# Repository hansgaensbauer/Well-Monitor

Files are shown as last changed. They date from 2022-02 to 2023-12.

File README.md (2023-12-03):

# Well Monitor
Well monitoring equipment for Engineers Without Borders

This hardware is for projects that require more monitoring than is possible with manual measurements taken by community members. The well monitor works by weighing a pipe or other weight suspended within the well, since the apparent weight of the pipe is directly proportional to the amount of the pipe left above water.

A photo of the well monitors before packaging
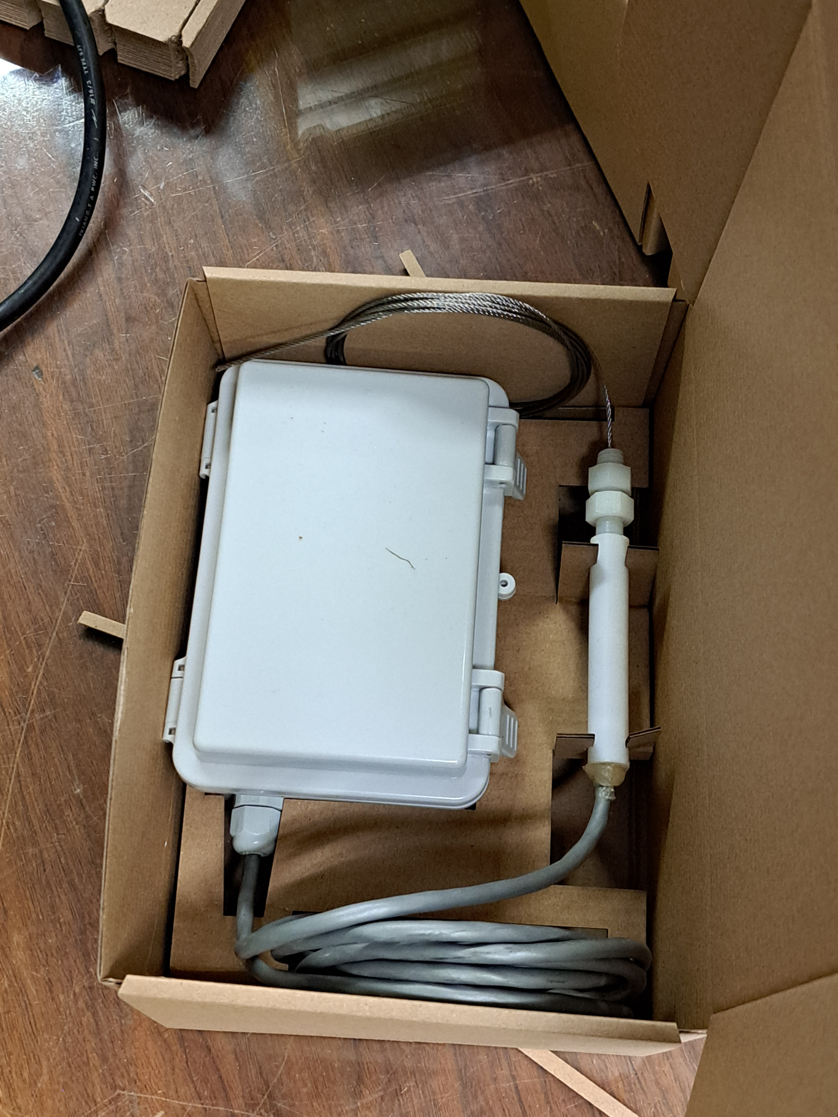
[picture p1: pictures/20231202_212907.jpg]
A well monitor in its packaging


## Installation and Use
The well monitor consists of two parts: a small "probe" that contains the load cell for weighing the pipe, and a separate box with the battery, USB flash drive, and readout electronics that gets mounted nearby. The probe requires a 3/8" hole to be drilled in the well cap over the location where the pipe is to be suspended. Remove one of the acetyl nuts on the bottom of the probe, thread the stainless-steel cable through the hole in the well cap, and reattach the nut on the other side to secure the probe. Mount the electronics box vertically against a wall or to a pole driven into the ground nearby. 

Since each well installation is different, the well monitor needs to be calibrated during installation:
1. Estimate the amount of pipe required to span the maximum expected variation in water level.
2. Calculate the maximum expected weight. This is the weight of the pipe and the cable used to suspend the pipe
3. Calculate the minimum expected weight. Calculate the buoyant force on the pipe with the water level at its highest expected level, and subtract this from the maximum weight.
4. Fill jugs of water to create "dummy" weights equal to the maximum and minimum weights, and one more equal to the difference between the maximum and minimum weights.
5. Disconnect the battery for the well monitor and remove the plastic cover that covers the electronics within the waterproof box.
6. Using clip leads, apply 9V to the indicated positions on the well monitor.
7. Use a multimeter to measure the voltage on the "Vout" testpoint indicated in the diagram.
8. Turn the "gain" potentiometer all the way to the left (counterclockwise).
9. Turn the "bias" potentiometer until the voltage on the multimeter just begins to increase above zero. Try to get the potentiometer to the very edge of the point where the voltage begins to increase.
10. Suspend the "difference" weight dummy from the well monitor. Ajust the "gain" potentiometer until the voltage reads close to 3.3V (it is clamped so that it cannot exceed this voltage).
11. Suspend the "minimum" weight dummy from the well monitor. Repeat step 9 to set the proper "zero weight" point.
12. Suspend the "maximum" weight dummy from the well monitor. The voltage should be near 3.3V. Make small adjustments to the gain and offset so that the voltage is as close as possible to zero when the minimum weight is attached, and as close as possible to 3.3V when the maximum weight is attached.

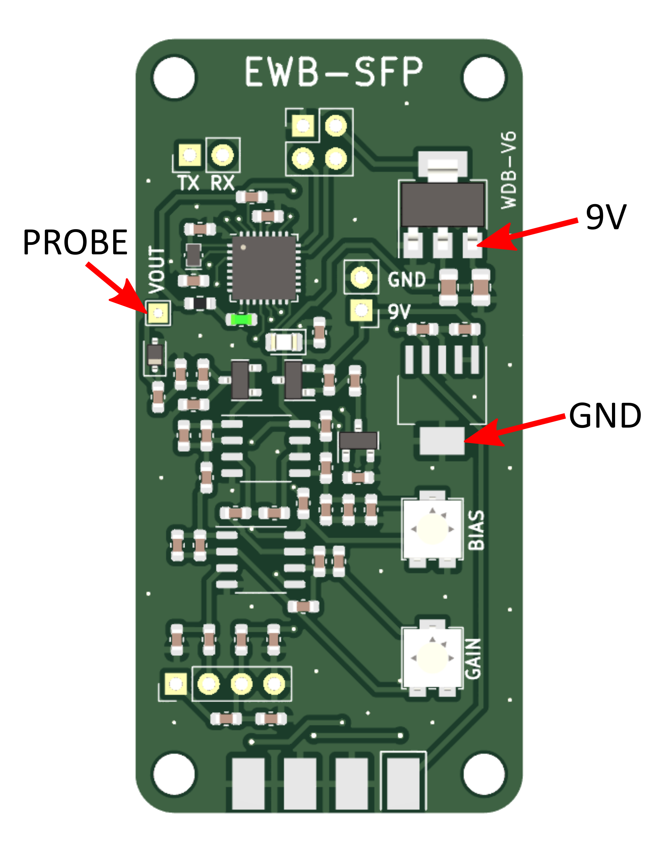
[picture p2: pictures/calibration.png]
Calibration Diagram


Once the battery is connected, measurements are saved once every three hours to a USB flash drive. To read the data, remove the flash drive and connect it to a computer. The file 'welldata.txt' will contain one line for each measurement, consisting of a measurement counter (to keep track of when measurements are restarted) followed by the measurement. The measurements are in "ADC Counts": a reading of 0 corresponds to zero volts, or the maximum water level when the well monitor is calibrated. A value of 32768 corresponds to 3.3V, or the minimum water level when the well monitor is calibrated.

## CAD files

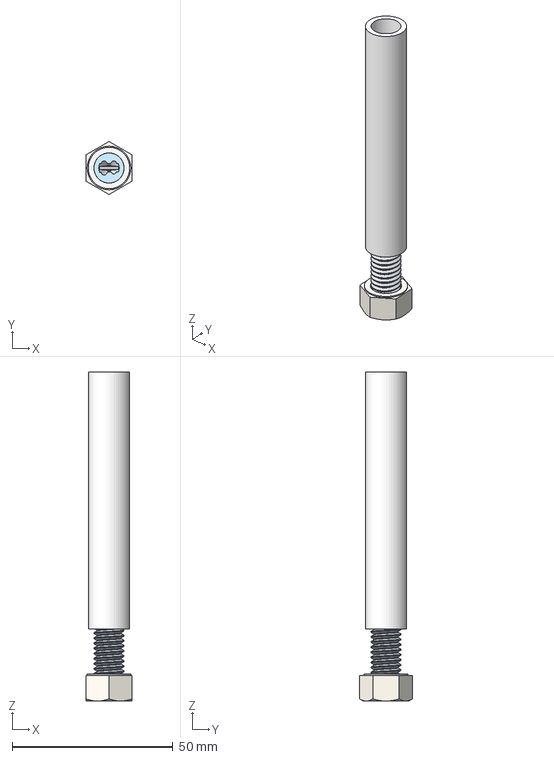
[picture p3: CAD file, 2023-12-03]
mechanical/WellMonitor_Probe.step
14.3 x 16.5 x 102.4 mm

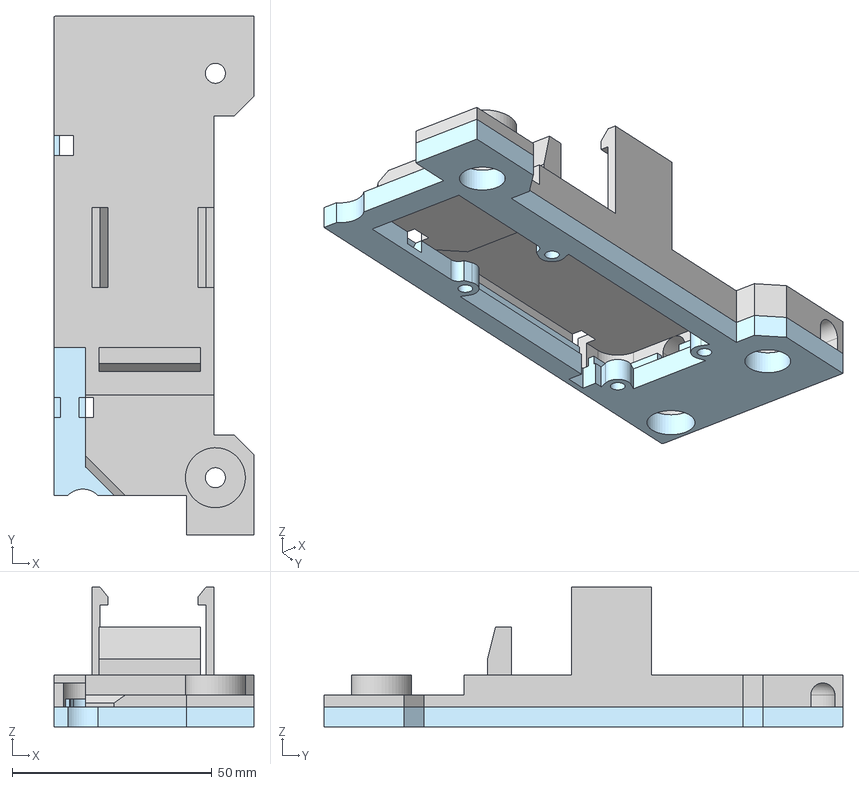
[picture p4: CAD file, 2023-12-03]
mechanical/WellMonitor_Case.step
50.0 x 129.7 x 35.0 mm

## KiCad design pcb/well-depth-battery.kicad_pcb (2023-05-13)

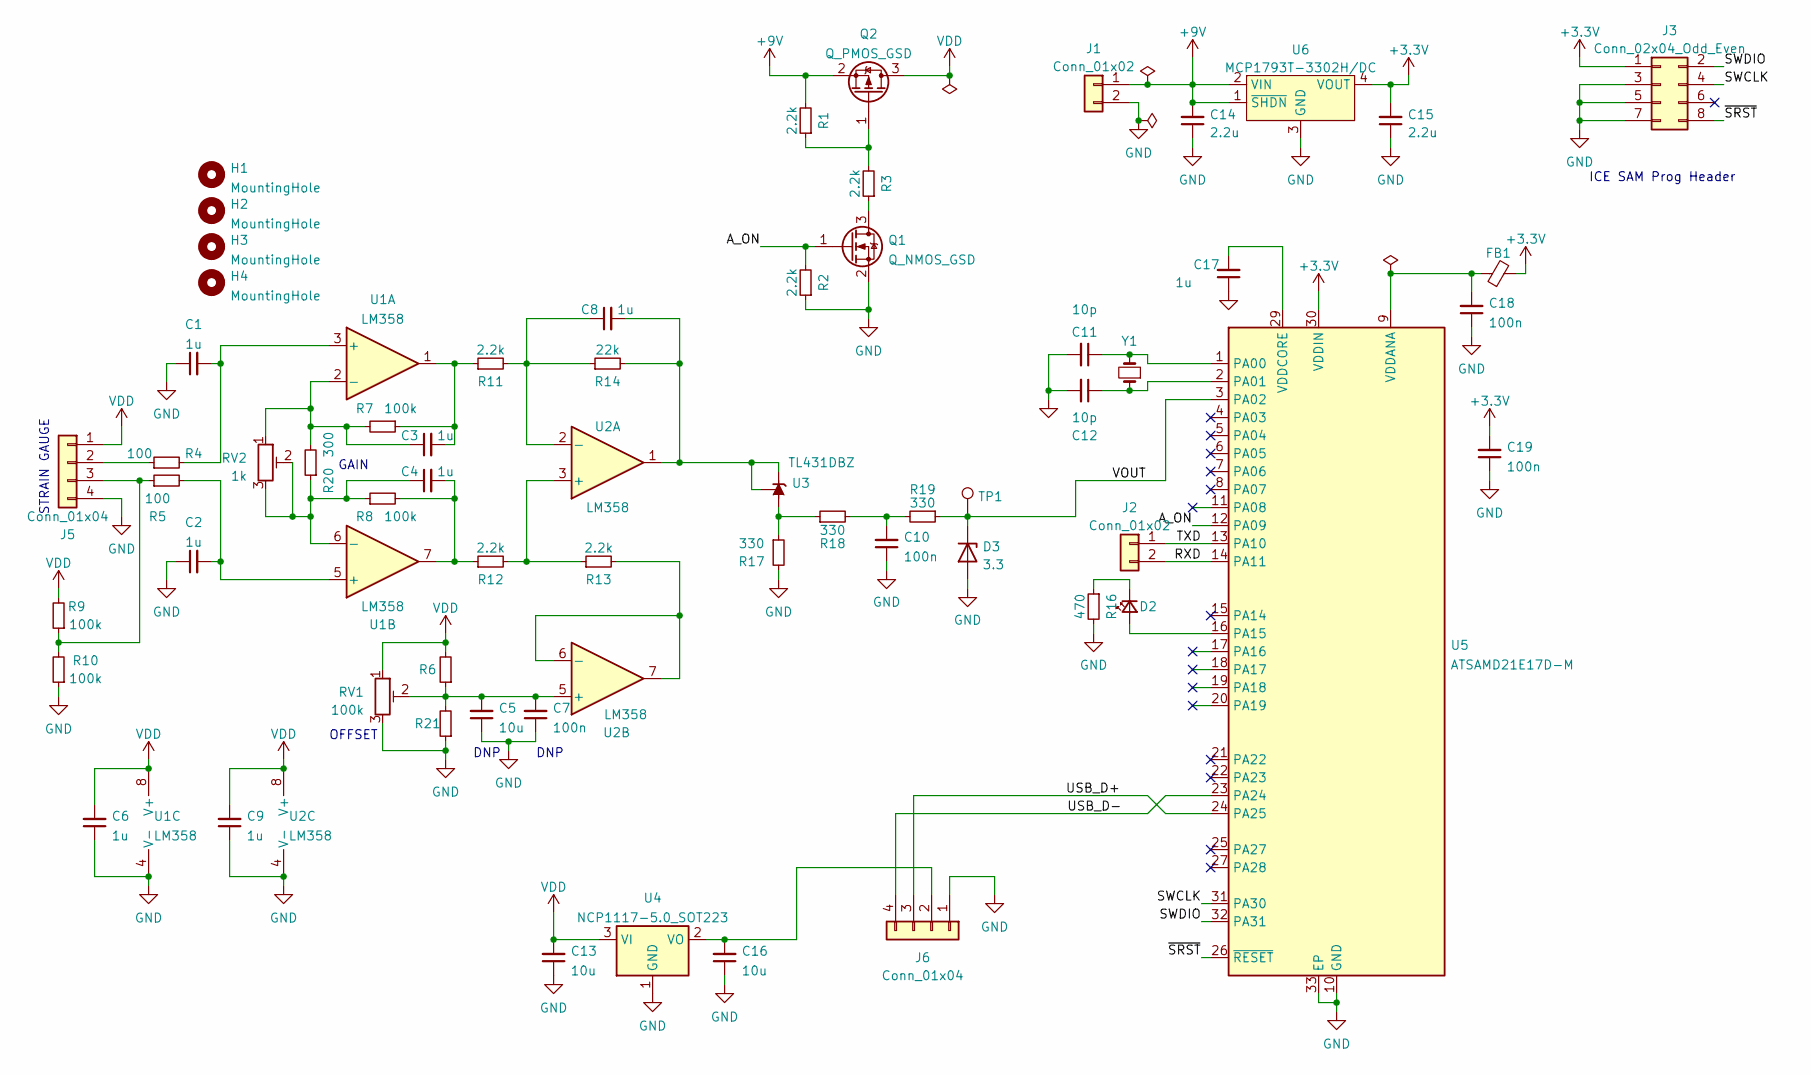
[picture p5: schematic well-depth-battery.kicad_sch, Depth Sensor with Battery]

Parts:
C1, C2, C3, C4, C6, C8, C9, C17: 1u; C_0603_1608Metric
C5: 10u; C_0603_1608Metric
C7, C10, C18, C19: 100n; C_0603_1608Metric
C11, C12: 10p; C_0603_1608Metric
C13, C16: 10u; C_0805_2012Metric
C14, C15: 2.2u; C_0603_1608Metric
D2: LED_Small; LED_0805_2012Metric
D3: 3.3; D_SOD-323
FB1: FerriteBead_Small; R_0603_1608Metric
H1, H2, H3, H4: MountingHole; MountingHole_3.2mm_M3
J1, J2: Conn_01x02; PinHeader_1x02_P2.54mm_Vertical
J3: Conn_02x04_Odd_Even; CardEdge_Prog
J5: Conn_01x04; PinHeader_1x04_P2.54mm_Vertical
J6: Conn_01x04; PinHeader_2x02_P2.54mm_Vertical
Q1: Q_NMOS_GSD; SOT-23
Q2: Q_PMOS_GSD; SOT-23
R1, R2, R3, R11, R12, R13: 2.2k; C_0603_1608Metric
R4, R5: 100; C_0603_1608Metric
R6, R21: C_0603_1608Metric
R7, R8, R9, R10: 100k; C_0603_1608Metric
R14: 22k; C_0603_1608Metric
R16: 470; C_0603_1608Metric
R17, R18, R19: 330; C_0603_1608Metric
R20: 300; C_0603_1608Metric
RV1: 100k; Potentiometer_Bourns_3314J_Vertical
RV2: 1k; Potentiometer_Bourns_3314J_Vertical
TP1: TestPoint; TestPoint_THTPad_1.5x1.5mm_Drill0.7mm
U1, U2: LM358; SOP-8_3.9x4.9mm_P1.27mm
U3: TL431DBZ; SOT-23
U4: NCP1117-5.0_SOT223; SOT-223-3_TabPin2
U5: ATSAMD21E17D-M; QFN-32-1EP_5x5mm_P0.5mm_EP3.6x3.6mm
U6: MCP1793T-3302H/DC; SOT-223-6
Y1: Crystal_Small; Crystal_SMD_MicroCrystal_CM9V-T1A-2Pin_1.6x1.0mm

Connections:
+3.3V: C15.2, C19.2, FB1.2, J3.1, U5.30 (VDDIN), U6.4 (VOUT)
+9V: C14.2, J1.1, Q2.2 (S), R1.2, U6.1 (~SHDN), U6.2 (VIN)
/A_ON: Q1.1 (G), R2.2, U5.12 (PA09)
/RXD: J2.2, U5.14 (PA11)
/SWCLK: J3.4, U5.31 (PA30)
/SWDIO: J3.2, U5.32 (PA31)
/TXD: J2.1, U5.13 (PA10)
/USB_D+: J6.3, U5.24 (PA25)
/USB_D-: J6.4, U5.23 (PA24)
/VOUT: D3.1 (K), R19.1, TP1.1, U5.3 (PA02)
/~SRST: J3.8, U5.26 (~RESET)
GND: C1.1, C2.1, C5.1, C6.1, C7.1, C9.1, C10.1, C11.2, C12.2, C13.1, C14.1, C15.1, C16.1, C17.1, C18.1, C19.1, D3.2 (A), J1.2, J3.3, J3.5, J3.7, J5.4, J6.1, Q1.2 (S), R2.1, R10.1, R16.2, R17.2, R21.1, RV1.3, U1.4 (V-), U2.4 (V-), U4.1 (GND), U5.10 (GND), U5.28 (GND), U5.33 (EP), U6.3 (GND), U6.6 (GND)
unnamed: C3.2, R7.1, R11.1, U1.1
unnamed: C4.2, R8.2, R12.1, U1.7
unnamed: C10.2, R18.2, R19.2
unnamed: D2.2 (A), U5.16 (PA15)
unnamed: D2.1 (K), R16.1
unnamed: J5.2, R4.1
unnamed: J5.3, R5.1, R9.1, R10.2
unnamed: C16.2, J6.2, U4.2 (VO)
unnamed: Q1.3 (D), R3.1
unnamed: Q2.1 (G), R1.1, R3.2
unnamed: C1.2, R4.2, U1.3 (+)
unnamed: C3.1, R7.2, R20.2, RV2.1, U1.2 (-)
unnamed: C2.2, R5.2, U1.5 (+)
unnamed: C4.1, R8.1, R20.1, RV2.2, RV2.3, U1.6 (-)
unnamed: R12.2, R13.1, U2.3 (+)
unnamed: C8.1, R11.2, R14.1, U2.2 (-)
unnamed: C5.2, C7.2, R6.1, R21.2, RV1.2, U2.5 (+)
unnamed: R13.2, U2.6 (-), U2.7
unnamed: R17.1, R18.1, U3.3 (A)
unnamed: C8.2, R14.2, U2.1, U3.1 (K), U3.2 (REF)
unnamed: C11.1, U5.1 (PA00), Y1.2
unnamed: C12.1, U5.2 (PA01), Y1.1
unnamed: C18.2, FB1.1, U5.9 (VDDANA)
unnamed: C17.2, U5.29 (VDDCORE)
VDD: C6.2, C9.2, C13.2, J5.1, Q2.3 (D), R6.2, R9.2, RV1.1, U1.8 (V+), U2.8 (V+), U4.3 (VI)

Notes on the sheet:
GAIN
OFFSET
DNP
STRAIN GAUGE
ICE SAM Prog Header

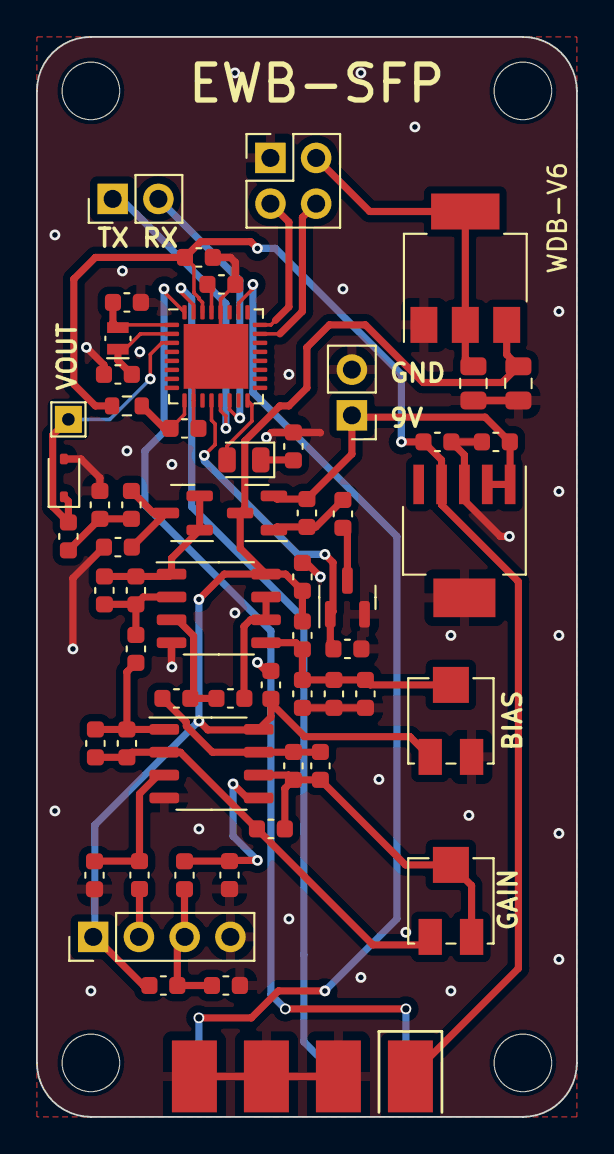
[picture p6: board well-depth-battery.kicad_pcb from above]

Board: 2 copper layers, 30.0 x 60.0 mm, 63 parts (0 on the bottom side), 37 nets.

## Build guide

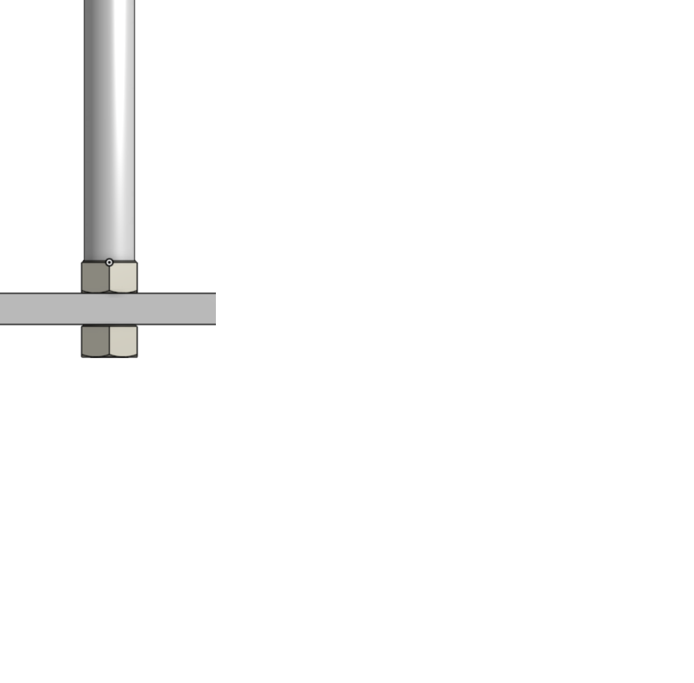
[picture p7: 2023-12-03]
pictures/probe installation.png

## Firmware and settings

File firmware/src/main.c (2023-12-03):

/**
 * \file
 *
 * \brief Empty user application template
 *
 */

/**
 * \mainpage User Application template doxygen documentation
 *
 * \par Empty user application template
 *
 * Bare minimum empty user application template
 *
 * \par Content
 *
 * -# Include the ASF header files (through asf.h)
 * -# Minimal main function that starts with a call to system_init()
 * -# "Insert application code here" comment
 *
 */

/*
 * Include header files for all drivers that have been imported from
 * Atmel Software Framework (ASF).
 */
/*
 * Support and FAQ: visit <a href="https://www.microchip.com/support/">Microchip Support</a>
 */
#include <asf.h>
#include <string.h>

#include "main.h"
#include "usart.h"
#include "adc.h"
#include "usb_flash.h"
#include "rtc_sleep.h"

//USB MSC SOF Counter. I added this
volatile static uint16_t main_usb_sof_counter = 0;

int main (void)
{
	system_init();
	rtc_init();
	delay_init();
	usart_init();
	adc_init();
	
	//Configure PA9 and PA15 as outputs
	PORT->Group[0].DIRSET.reg = PORT_PA09 | PORT_PA15;
	
	int meas_idx = 0; //This will go back to zero on reset
	
	while(true){
		debug_print("Waking Up\n\r");
		analog_on();
		led_on();
		
		uhc_start();
		delay_s(2);
		
		int acc = 0;
		//Read the strain gauge ADC value and average
		for(int i = 0; i < NUMSAMPLES; i++){
			acc += adc_read();
		}
		usb_writedata(acc, meas_idx++);
		debug_print("Sleeping\n\n\r");
		
		analog_off();
		rtc_init();
		standby();
	}
}

void analog_on(){
	PORT->Group[0].OUTSET.reg = PORT_PA09;
}

void analog_off(){
	PORT->Group[0].OUTCLR.reg = PORT_PA15 | PORT_PA09;
}

void led_on(){
	PORT->Group[0].OUTSET.reg = PORT_PA15;
}

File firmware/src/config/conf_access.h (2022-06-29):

/*****************************************************************************
 *
 * \file
 *
 * \brief Memory access control configuration file.
 *
 * This file contains the possible external configuration of the memory access
 * control.
 *
 * Copyright (c) 2009-2018 Microchip Technology Inc. and its subsidiaries.
 *
 * \asf_license_start
 *
 * \page License
 *
 * Subject to your compliance with these terms, you may use Microchip
 * software and any derivatives exclusively with Microchip products.
 * It is your responsibility to comply with third party license terms applicable
 * to your use of third party software (including open source software) that
 * may accompany Microchip software.
 *
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
 * \asf_license_stop
 *
 ******************************************************************************/
/*
 * Support and FAQ: visit <a href="https://www.microchip.com/support/">Microchip Support</a>
 */


 //! Configuration of ctrl_access which is an abstraction layer for memory interfaces (common/services/storage/ctrl_access)

#ifndef _CONF_ACCESS_H_
#define _CONF_ACCESS_H_

#include "compiler.h"
#include "board.h"


/*! \name Activation of Logical Unit Numbers
 */
//! @{
#ifdef VIRTUAL_MEMORY_ENABLE
#define LUN_0                ENABLE   //!< Enable On-Chip Virtual Memory.
#else
#define LUN_0                DISABLE  //!< Disable On-Chip Virtual Memory.
#endif

#ifdef AT45DBX_ENABLE
#define LUN_1                ENABLE   //!< Enable AT45DBX Data Flash.
#else
#define LUN_1                DISABLE  //!< Disable AT45DBX Data Flash.
#endif

//! New setting for SD/MMC stack in common folder
#ifdef SD_MMC_ENABLE
#define LUN_2                ENABLE   //!< Enable common SD/MMC stack
#define LUN_3                ENABLE
#else
#define LUN_2                DISABLE  //!< Disable common SD/MMC stack
#define LUN_3                DISABLE
#endif

//! Old setting for SD/MMC stack in AVR folder
#ifdef SD_MMC_SPI_ENABLE
#define LUN_4                ENABLE   //!< Enable SD/MMC Card over SPI or SPI.
#else
#define LUN_4                DISABLE  //!< Disable SD/MMC Card over SPI or SPI.
#endif

//! Old setting for SD/MMC stack in AVR folder
#ifdef SD_MMC_MCI_ENABLE
#define LUN_5                ENABLE   //!< Enable SD/MMC Card over MCI or MCI.
#else
#define LUN_5                DISABLE  //!< Disable SD/MMC Card over MCI or MCI.
#endif

#define LUN_6                DISABLE
#define LUN_7                DISABLE

#ifdef USB_MASS_STORAGE_ENABLE
#define LUN_USB              ENABLE   //!< Enable Host Mass-Storage Memory.
#else
#define LUN_USB              DISABLE  //!< Disable Host Mass-Storage Memory.
#endif

//! @}

/*! \name LUN 0 Definitions
 */
//! @{
#define VIRTUAL_MEM                             LUN_0
#define LUN_ID_VIRTUAL_MEM                      LUN_ID_0
#define LUN_0_INCLUDE                           "virtual_mem.h"
#define Lun_0_test_unit_ready                   virtual_test_unit_ready
#define Lun_0_read_capacity                     virtual_read_capacity
#define Lun_0_unload                            NULL /* Can not be unloaded */
#define Lun_0_wr_protect                        virtual_wr_protect
#define Lun_0_removal                           virtual_removal
#define Lun_0_usb_read_10                       virtual_usb_read_10
#define Lun_0_usb_write_10                      virtual_usb_write_10
#define Lun_0_mem_2_ram                         virtual_mem_2_ram
#define Lun_0_ram_2_mem                         virtual_ram_2_mem
#define LUN_0_NAME                              "\"On-Chip Virtual Memory\""
//! @}

/*! \name LUN 1 Definitions
 */
//! @{
#define AT45DBX_MEM                             LUN_1
#define LUN_ID_AT45DBX_MEM                      LUN_ID_1
#define LUN_1_INCLUDE                           "at45dbx_mem.h"
#define Lun_1_test_unit_ready                   at45dbx_test_unit_ready
#define Lun_1_read_capacity                     at45dbx_read_capacity
#define Lun_1_unload                            NULL /* Can not be unloaded */
#define Lun_1_wr_protect                        at45dbx_wr_protect
#define Lun_1_removal                           at45dbx_removal
#define Lun_1_usb_read_10                       at45dbx_usb_read_10
#define Lun_1_usb_write_10                      at45dbx_usb_write_10
#define Lun_1_mem_2_ram                         at45dbx_df_2_ram
#define Lun_1_ram_2_mem                         at45dbx_ram_2_df
#define LUN_1_NAME                              "\"AT45DBX Data Flash\""
//! @}

/*! \name LUN 2 Definitions
 */
//! @{
#define SD_MMC_0_MEM                            LUN_2
#define LUN_ID_SD_MMC_0_MEM                     LUN_ID_2
#define LUN_2_INCLUDE                           "sd_mmc_mem.h"
#define Lun_2_test_unit_ready                   sd_mmc_test_unit_ready_0
#define Lun_2_read_capacity                     sd_mmc_read_capacity_0
#define Lun_2_unload                            sd_mmc_unload_0
#define Lun_2_wr_protect                        sd_mmc_wr_protect_0
#define Lun_2_removal                           sd_mmc_removal_0
#define Lun_2_usb_read_10                       sd_mmc_usb_read_10_0
#define Lun_2_usb_write_10                      sd_mmc_usb_write_10_0
#define Lun_2_mem_2_ram                         sd_mmc_mem_2_ram_0
#define Lun_2_ram_2_mem                         sd_mmc_ram_2_mem_0
#define LUN_2_NAME                              "\"SD/MMC Card Slot 0\""
//! @}

/*! \name LUN 3 Definitions
 */
//! @{
#define SD_MMC_1_MEM                            LUN_3
#define LUN_ID_SD_MMC_1_MEM                     LUN_ID_3
#define LUN_3_INCLUDE                           "sd_mmc_mem.h"
#define Lun_3_test_unit_ready                   sd_mmc_test_unit_ready_1
#define Lun_3_read_capacity                     sd_mmc_read_capacity_1
#define Lun_3_unload                            sd_mmc_unload_1
#define Lun_3_wr_protect                        sd_mmc_wr_protect_1
#define Lun_3_removal                           sd_mmc_removal_1
#define Lun_3_usb_read_10                       sd_mmc_usb_read_10_1
#define Lun_3_usb_write_10                      sd_mmc_usb_write_10_1
#define Lun_3_mem_2_ram                         sd_mmc_mem_2_ram_1
#define Lun_3_ram_2_mem                         sd_mmc_ram_2_mem_1
#define LUN_3_NAME                              "\"SD/MMC Card Slot 1\""
//! @}
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

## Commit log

2021-11-02 First Pass Schematic
    [well-monitor.kicad_pcb, well-monitor.sch]
2021-11-03 First pass routing and DRC/ERC pass
    [well-monitor.kicad_pcb, well-monitor.sch]
2021-11-03 Update README with device photos
2021-11-10 Received hardware, started implementing software
    Arduino IDE compatibility works, and SD card data logging has been tested and is functional.
    [well-monitor-B_Cu.gbr, well-monitor-B_Mask.gbr, well-monitor-B_Paste.gbr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]
2021-11-11 V1 (Fix issues with V0)
    [well-monitor.kicad_pcb, well-monitor.sch]
2021-11-12 Created arduino-style pinout
2021-11-12 Added RTC functionality
    [well-monitor.kicad_pcb]
2022-02-09 Well Monitor: Update to newest KiCAD version
    Also updated CAM files
    [well-monitor-B_Cu.gbr, well-monitor-B_Mask.gbr, well-monitor-B_Paste.gbr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]
2022-02-09 Depth Sensor: Add depth sensor simulations
    Basic simulations to confirm the general behavior of the depth sensor INA
2022-02-09 Depth Sensor: Create Schematic
    Created KiCAD schematic for the depth sensor amplifier
2022-02-09 Depth Sensor: Add KiCAD files
    [depth-sensor.kicad_pcb, depth-sensor.kicad_sch]
2022-02-09 Depth-Sensor: Routing and PCB layout
    Also update .gitignore to KiCAD 6
    [depth-sensor.kicad_pcb, depth-sensor.kicad_sch]
2022-02-09 Depth Sensor: CAM
    Also fixed folder structure
    [depth-sensor-B_Cu.gbr, depth-sensor-B_Mask.gbr, depth-sensor-B_Paste.gbr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]
2022-02-09 Depth Sensor: Create zip for fab
2022-02-09 Project: remove obsolete copies from directory
    [depth-sensor.kicad_sch]
2022-02-10 WDMP: Add photo of assembled hardware
2022-04-06 Well Depth Battery: Create Schematic
    Schematic ERC pass.
    [well-depth-battery.kicad_pcb, well-depth-battery.kicad_sch]
2022-04-07 Project: Rearrange the Project
    Move all different devices to their own high-level folders.
    [depth-sensor-B_Cu.gbr, depth-sensor-B_Mask.gbr, depth-sensor-B_Paste.gbr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]
2022-04-08 WDB: Floorplanning
    Also fixed .gitignore to not ignore lib
    [well-depth-battery.kicad_pcb, well-depth-battery.kicad_sch]
2022-04-08 Project: Fix KiCAD libraries
2022-04-09 WDB: New Board Outline
    [well-depth-battery.kicad_pcb]
2022-04-09 WDB: Layout and CAM
    [well-depth-battery-B_Cu.gbr, well-depth-battery-B_Mask.gbr, well-depth-battery-B_Paste.gbr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]
2022-04-18 Add photos of WDB assembly
2022-05-03 Start WDB Refactor w/ SAMD21
    [well-depth-battery.kicad_sch]
2022-05-04 WDB: ERC Pass
    [well-depth-battery.kicad_sch]
2022-05-04 WDB: DRC Pass and Fab
    [well-depth-battery-B_Cu.gbr, well-depth-battery-B_Mask.gbr, well-depth-battery-B_Paste.gbr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]
2022-06-20 Fix wdb Firmware Project
    Compiles, blinks LED
    [conf_clocks.h]
2022-06-20 FW: UART Working
2022-06-21 FW: ADC Setup Complete
2022-06-21 FW: ADC Driver Works
2022-06-23 FW: Draft RTC Driver (nonfunctional)
2022-06-23 FW: Fix RTC Driver
    Interrupts working
    [conf_clocks.h, main.c]
2022-06-28 FW: UHC Causes RTC Problem
    [adc.c, main.c]
2023-05-11 removed sd card
    [well-depth-battery.kicad_sch]
2023-05-11 First pass routing for rectangular board
    [well-depth-battery.kicad_pcb, well-depth-battery.kicad_sch]
2023-05-13 redo routing, DRC/ERC pass
    [well-depth-battery.kicad_pcb, well-depth-battery.kicad_sch]
2023-05-13 Fix prog connector
    [well-depth-battery.kicad_pcb, well-depth-battery.kicad_sch]
2023-12-03 Remove old well monitor versions to prioritize WDB-V6
    [depth-sensor-B_Cu.gbr, depth-sensor-B_Mask.gbr, depth-sensor-B_Paste.gbr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]
2023-12-03 Add mechanical components, move firmware
    [WellMonitor_Case.step, WellMonitor_Probe.step]
2023-12-03 Fix whitespace in calibration diagram
2023-12-03 Second calibration figure improvements
